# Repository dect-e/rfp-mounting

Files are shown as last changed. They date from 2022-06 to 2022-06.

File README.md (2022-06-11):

Mounting plates for Mitel RFPs
==============================

This repository contains two directories:

- `dimensions` contains drawings and measurements of the RFPs' mounting holes
- `things` adapts those measurements into mounting plate designs, ready to be
  laser-cut or 3D-printed

Currently, we only have measurements and designs for the 2nd/3rd generation
indoor RFPs (RFP 32, 42, 35, and 43), which all use the same plastic case.  
1st and 4th generation, as well as outdoor, RFPs have a different form factor,
so would require a completely different mounting plate design.

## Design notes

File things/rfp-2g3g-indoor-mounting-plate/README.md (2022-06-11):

Mitel RFP43 mounting plate
==========================

The files in this directory contain a mounting plate designed for the two
mounting holes on the back of an RFP43. All 2nd/3rd gen indoor RFPs will have
virtually identical holes.

The dxf file can be directly used as input for a laser cutter.

We have verified the correct placement of the mounting holes
with a proof-of-concept cut on 5 mm wood composite board.

For real-world usage, we plan to use acrylic glass to make the plate
splinter-free and more resistant against gaffer tape.  
We anticipate that 4 mm acrylic glass should provide sufficient strength
(especially for tight ziptie mounting).

Features
--------

- 2 holes for M4 screws to hook the RFP onto.
- 3 holes for 5mm-headed nails to latch into the RFP's "feet" (to prevent it
  from accidentally slipping off the hooking screws).  
  The 2 + 1 holes are placed such that the RFP can be latched both
  ethernet port up and ethernet port down.
- 3 triangular holes (protruding above the RFP case) to hang the plate onto
  wall screws/hooks.
- 2 holes near the top through which a hanging wire loop can be fed.
- A variety of slots for zip-tying the plate to a pole (vertical or
  horizontal), grate, fence, or similar.
- 5 cm clearance from both the top and bottom of the plate to the nearest RFP
  case protrusion, to allow the plate to be gaffer-taped to a surface before
  hooking in the RFP (and not having the tape obstruct any of the RFP's
  mounting points).

Suggested material
------------------

- Wood or acrylic glass plate (approx. 4 mm thickness should be ideal)
- 2 × M4 8 mm screws (to hook the RFP onto)
- (optionally:) 3 × nails, 4 mm or 5 mm head diameter, min. 4 mm length (to
  latch the RFP in place)

Files
-----

- The svg file serves as the source of information; it contains separate
  layers, so the RFP's holes, ziptie slots, and hanging holes can all be
  hidden/shown individually.
- The dxf file has been exported from the svg and is ready to be laser-cut.
- The "dimension" files are identical to the main dxf, but contain measurement
  markings (measured on the drawing, which is in turn based on actual physical
  measurements). Do not use it for laser cutting, unless you want an art piece
  with lasered-in measurement numbers. ;)

All measurements are in millimeters, usually with a resolution and accuracy of
approx. 0.1 mm.

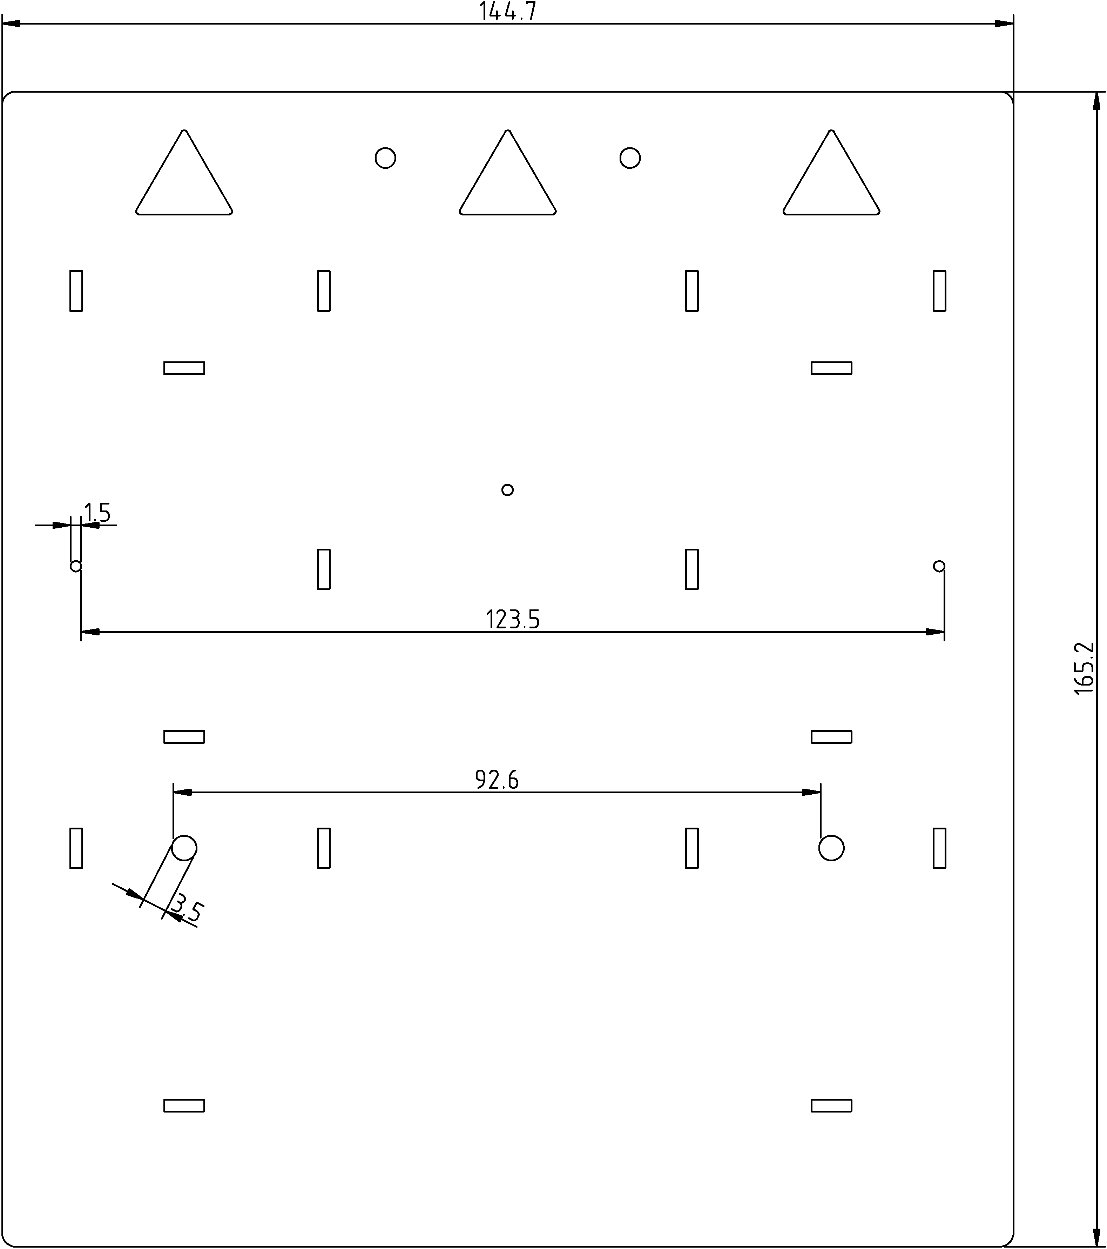
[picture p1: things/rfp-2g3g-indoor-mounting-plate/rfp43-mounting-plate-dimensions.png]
Mounting plate design for RFP43


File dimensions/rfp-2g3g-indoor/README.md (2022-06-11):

Mitel RFP43 mounting holes
==========================

The files in this directory contain the dimensions of the two mounting holes on
the back of an RFP43. All 2nd/3rd gen indoor RFPs will have virtually identical
holes.

For mounting, you can hook the RFP onto an M4 screw.  
M5 also fits into the mounting hole, but will usually have a bigger screw head
that only fits into the insertion slot if you tilt/wiggle the RFP
forwards/backwards.

The screw should protrude approx. 4 mm (not including the head) from your
mounting plate.

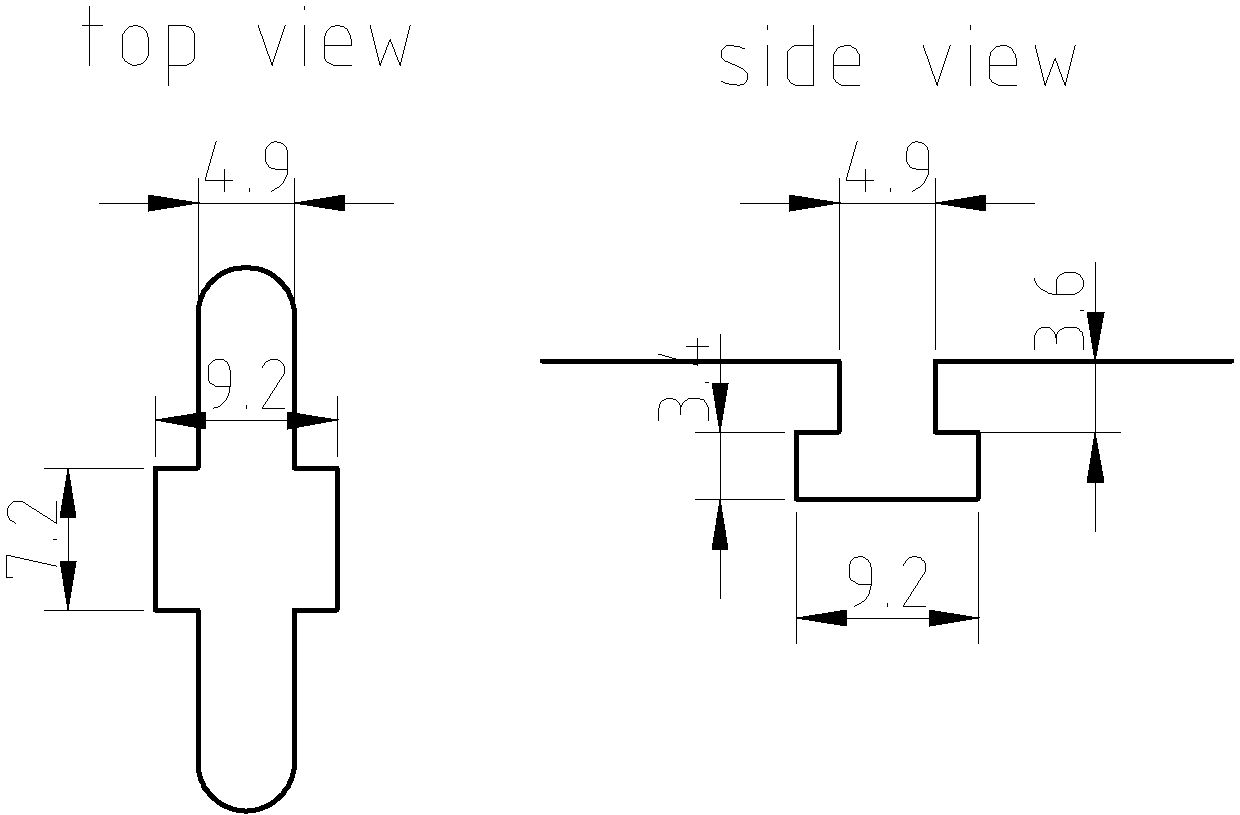
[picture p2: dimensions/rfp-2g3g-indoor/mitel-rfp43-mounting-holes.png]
Drawing of mounting hole dimensions


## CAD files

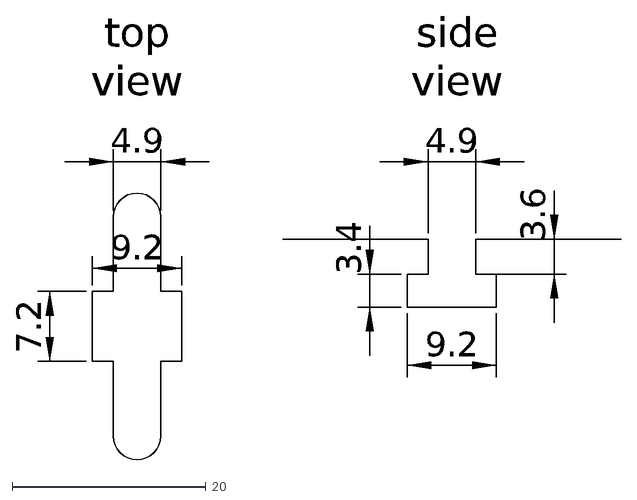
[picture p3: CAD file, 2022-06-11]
dimensions/rfp-2g3g-indoor/mitel-rfp43-mounting-holes.dxf
4.9
9.2
7.2
top view
side view
3.6
3.4

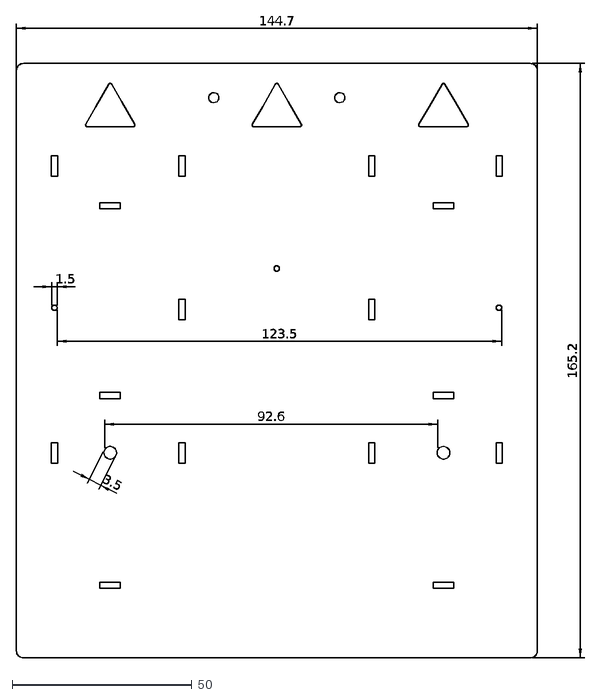
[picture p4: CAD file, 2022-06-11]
things/rfp-2g3g-indoor-mounting-plate/rfp43-mounting-plate-dimensions.dxf
3.5
92.6
1.5
123.5
144.7
165.2

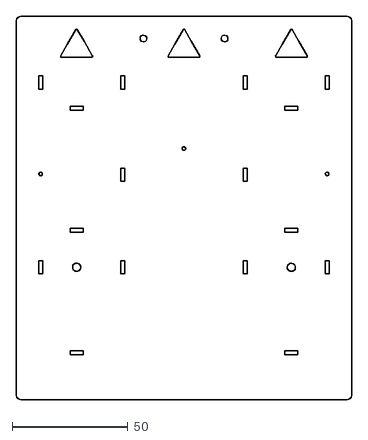
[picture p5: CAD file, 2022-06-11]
things/rfp-2g3g-indoor-mounting-plate/rfp43-mounting-plate.dxf
144.7 x 165.2

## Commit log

2022-06-11 RFP43 mounting hole dimensions
    [mitel-rfp43-mounting-holes.dxf]
2022-06-11 Add mounting plate (unfinished version 1!)
    [rfp43-mounting-plate.dxf]
2022-06-11 Corrected version of mounting plate
    [rfp43-mounting-plate-dimensions.dxf, rfp43-mounting-plate.dxf]
